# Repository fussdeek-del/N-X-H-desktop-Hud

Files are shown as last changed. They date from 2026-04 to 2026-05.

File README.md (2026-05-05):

# N X H — The Desktop HUD

     

> A always-on hardware HUD that sits on ur desk and shows live CPU, RAM, DISK, FPS and TIME — no alt-tabbing, no task manager, just plug and go.

---

## What is it?

NXH is a compact always-on HUD built around the Raspberry Pi Pico. It plugs into any PC via USB-C and shows live system stats CPU usage, RAM, disk, FPS, and time on a 2.4" ST7789V TFT display (240×320, SPI). The whole thing sits in a custom 3D-printed enclosure I designed in FreeCAD. No software window to manage, no hotkeys, it is just always there on ur desk showing you what ur PC is doing.

## Why I built it

My PC isn't that powerful tbh. Whenever I push it on gaming, rendering, compiling I always needed to know if it's hitting the limit. Opening task manager takes too long and gets in the way. I wanted something that just *sits there* and tells me. So I built it. Hack Club gave me the chance to actually do it for real, with a proper coustum PCBs and everything. Huge shout out to them 🙌

---

## Demo

<p align="center">
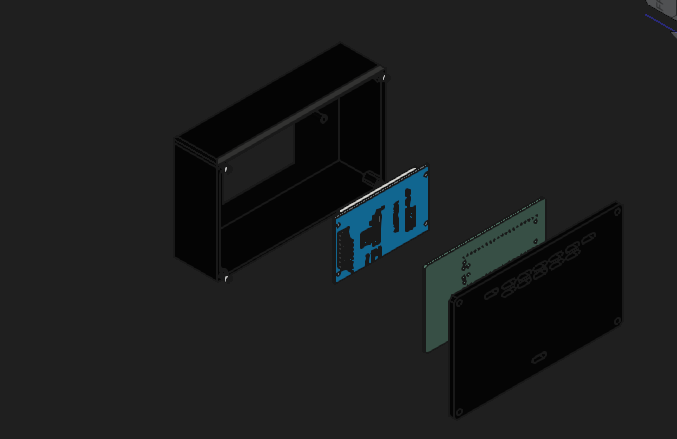
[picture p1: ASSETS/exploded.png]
Exploded 3D view
  
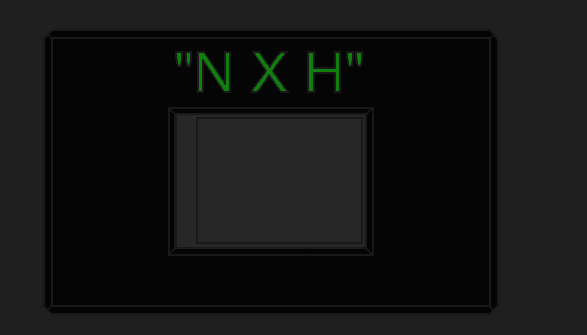
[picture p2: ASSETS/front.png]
Front panel view
  
</p>

<p align="center">
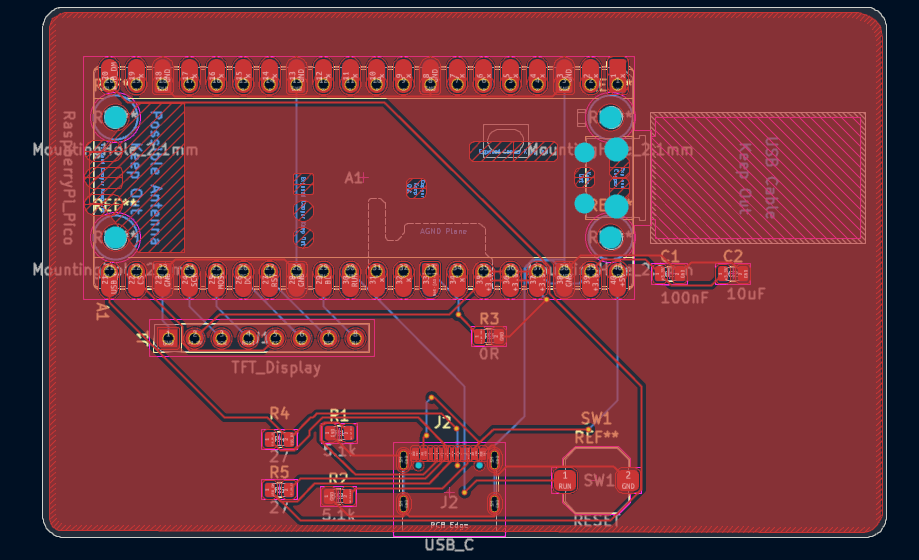
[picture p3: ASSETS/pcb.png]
PCB layout
  
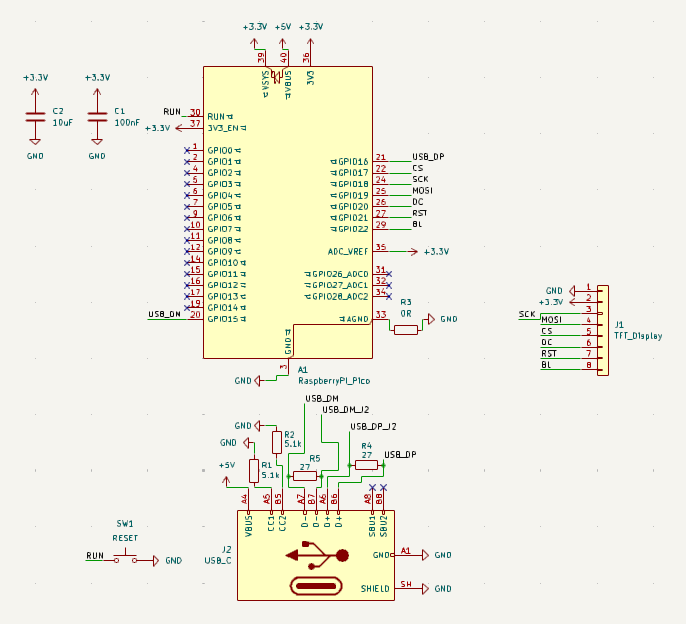
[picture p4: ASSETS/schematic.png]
Full schematic
  
</p>

<p align="center">
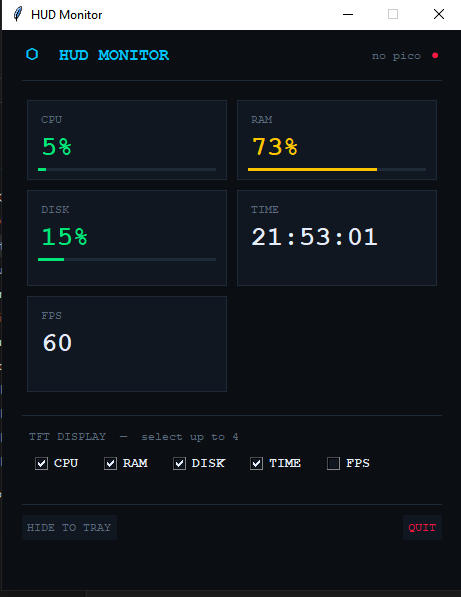
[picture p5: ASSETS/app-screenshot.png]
HUD Monitor companion app
  
</p>

---

## Features

- Raspberry Pi Pico (RP2040) as the main MCU
- 2.4" ST7789V TFT display  240×320, SPI, 3.3V
- USB-C connectivity (power + data, no drivers needed)
- Custom 2-layer PCB designed from scratch in KiCad
- 3D-printed enclosure designed in FreeCAD back lid, front panel, internal mounts
- C++ firmware running on the Pico
- Lightweight companion desktop app (Python) select which stats to display
- Hardware reset button (SW1) wired to RUN pin
- Onboard decoupling capacitors on the 3.3V rail (100nF + 10µF)
- Displays: CPU %, RAM %, Disk %, FPS, System Time

---

## Hardware

| Component | Spec | Qty | Price | Link |
|---|---|---|---|---|
| Raspberry Pi Pico | RP2040, 2MB flash — must be original with TP1/TP2/TP3 test pads | ×1 | $3.53 | [Buy](https://www.aliexpress.com/item/1005008948799927.html) |
| 2.4" TFT Display | ST7789V driver, 240×320, SPI, 8-pin, 3.3V | ×1 | $4.47 | [Buy](https://www.aliexpress.com/item/1005009546154656.html) |
| USB-C Connector | Female SMD 16-pin, horizontal mount, USB 2.0 — GCT USB4105-GF-A footprint | ×1 (pack of 5) | $1.17 | [Buy](https://www.aliexpress.com/item/1005008515699009.html) |
| Resistor 5.1kΩ 0805 | R1, R2 — CC1/CC2 USB-C pull-downs | ×2 (pack of 100) | $1.72 | [Buy](https://www.aliexpress.com/item/1005009613956367.html) |
| Resistor 27Ω 0805 | R4, R5 — USB D+/D− series resistors | ×2 (pack of 100) | $0.46 | [Buy](https://www.aliexpress.com/item/32997835881.html) |
| Resistor 0Ω 0805 | R3 — AGND to GND bridge jumper | ×1 (pack of 100) | $0.71 | [Buy](https://www.aliexpress.com/item/1005007446894308.html) |
| Capacitor 100nF 0805 | C1 — 3.3V rail decoupling, 50V X7R ceramic | ×1 (pack of 100) | $6.11 | [Buy](https://www.aliexpress.com/item/1005012084340996.html) |
| Capacitor 10µF 0805 | C2 — 3.3V rail bulk cap, 10V X5R ceramic | ×1 (pack of 50) | $2.30 | [Buy](https://www.aliexpress.com/item/32911735940.html) |
| Tactile Push Button | 6×6mm SMD 4-pin, 4.3mm height — SW1 reset | ×1 (pack of 20) | $1.95 | [Buy](https://www.aliexpress.com/item/1005006870418414.html) |
| Male Pin Header 2.54mm | Single row 40-pin (snap to 8) — J1 TFT connector | ×1 | $0.90 | [Buy](https://www.aliexpress.com/item/32670970932.html) |
| PCB Manufacturing | 2-layer, FR-4, 1.6mm, HASL — upload Gerber to JLCPCB | ×5 boards | $3.00 | [JLCPCB](https://jlcpcb.com) |
| 3D Enclosure | Custom HUD case — upload STL to JLC3DP | ×1 | $16.78 | [JLC3DP](https://jlc3dp.com) |
| M2 × 6mm Screw + Nut | Stainless steel — 4 sets mount PCB and Pico to case posts | ×4 sets (kit of 50) | $0.30 | [Buy](https://www.aliexpress.com/item/1005003157957734.html) |
| M3 × 10mm Screw + Nut | Stainless steel — 4 sets close the back lid | ×4 sets (kit of 50) | $0.30 | [Buy](https://www.aliexpress.com/item/1005003157957734.html) |
| USB-A to USB-C Cable | 1m, data + power capable (not charge-only) | ×1 | $1.90 | [Buy](https://www.aliexpress.com/item/1005006121990031.html) |
| USB-C Extension Cable | USB-C 3.1 Gen2, PD 100W, 5A — optional if ur port is hard to reach | ×1 | $2.42 | [Buy](https://www.aliexpress.com/item/1005006904002741.html) |

[`BOM components.csv`](BOM%20components.csv)

---

## How to use

## Build & Installation Guide

### Parts needed
See full BOM table above with links.

### PCB Assembly
1. Order PCB using gerbers.zip from JLCPCB
2. Solder SMD components first: R1, R2 (5.1k), R3 (0Ω), R4, R5 (27Ω), C1 (100nF), C2 (10uF), SW1
3. Solder USB-C connector J2
4. Place Raspberry Pi Pico on pin headers
5. Connect TFT display to J1 connector

### Flash Firmware
1. Hold BOOTSEL on Pico and plug USB-C
2. Copy FIRMWARE/hud-firmware/SRC/main.cpp compiled .uf2 to the drive
3. Pico reboots automatically

### Run the companion app

1. Make sure Python is installed — if not, [download it here](https://python.org)
2. Install dependencies:
   ```
   pip install -r app/requirements.txt
   ```
3. Run the app:
   ```
   python app/main.py
   ```
4. The HUD Monitor window opens — tick which stats you want shown on the display (CPU, RAM, DISK, TIME, FPS)
5. The device updates in real time as long as it's connected

> The app talks to the Pico over serial (USB). If it says "no pico" in the top right, unplug and replug the USB-C cable.

---

## Repo structure

```
NXH/
├── README.md
├── BOM components.csv
│
├── APP/
│   └── hud-app/
│       ├── main.py
│       ├── config.py
│       ├── metrics.py
│       ├── tray.py
│       ├── hud_settings.json
│       └── core/
│           ├── formatter.py
│           ├── metrics.py
│           ├── sender.py
│           └── __init__.py
│
├── ASSETS/
│   ├── banner.png
│   ├── exploded.png
│   ├── front.png
│   ├── pcb.png
│   ├── schematic.png
│   ├── app-screenshot.png
│   ├── wiring.png
│   └── zine-page.png
│
├── CAD/
│   ├── HUD case neww.FCStd          ← FreeCAD source
│   ├── HUD case new.step            ← full assembly export
│   ├── PCB new.step                 ← PCB 3D model
│   └── Display TFT-ST7789-240X320 V2.step
│
├── FIRMWARE/
│   └── hud-firmware/
│       ├── platformio.ini
│       └── SRC/
│           └── main.cpp
│
└── PCB/
    ├── gerber new.zip               ← submit this to JLCPCB
    └── PCB new/
        ├── real PCB.kicad_pro
        ├── real PCB.kicad_sch
        └── real PCB.kicad_pcb
```
---

## Wiring diagram

| Pico pin | TFT pin | Signal |
|---|---|---|
| GP17 | CS | Chip select |
| GP18 | SCK | SPI clock |
| GP19 | MOSI | SPI data |
| GP20 | DC | Data/command |
| GP21 | RST | Reset |
| GP22 | BL | Backlight |
| 3V3 (pin 36) | VCC | 3.3V power |
| GND (pin 38) | GND | Ground |

---

## Zine page

*Made for Hack Club Fallout -- Shenzhen 2025*

<p align="center">
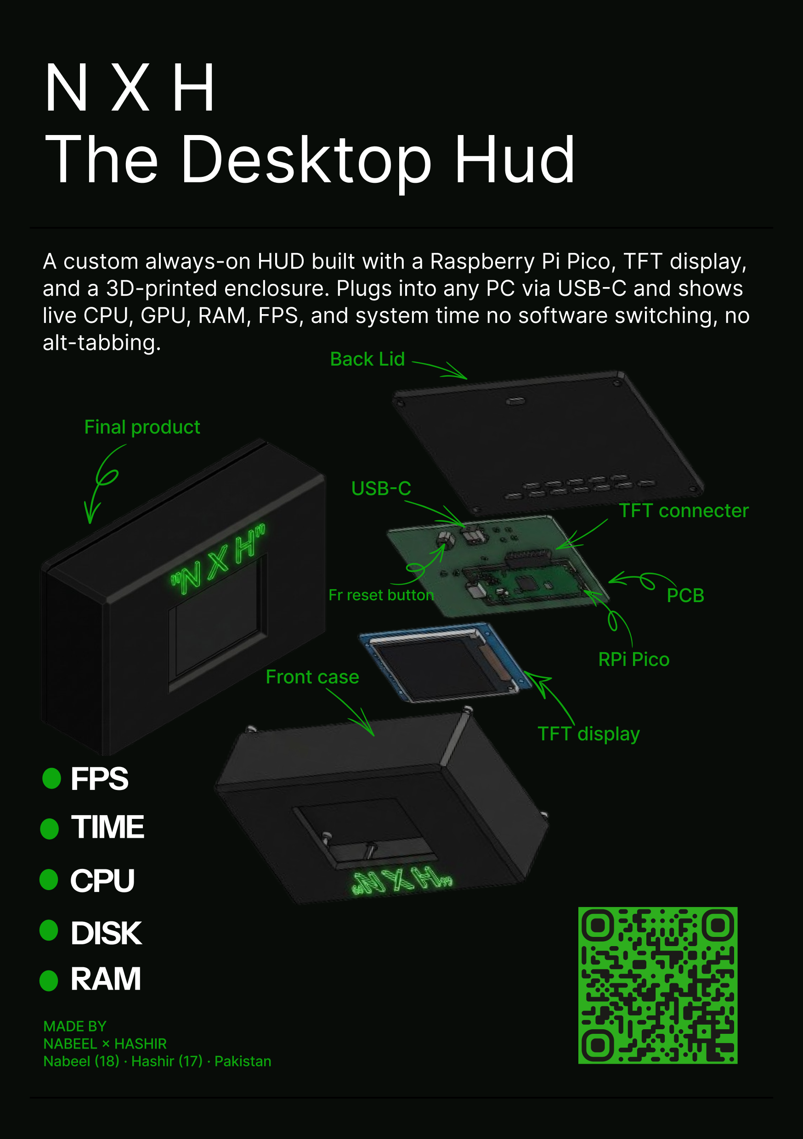
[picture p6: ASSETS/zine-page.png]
NXH Zine page — Nabeel x Hashir, Pakistan
  
</p>

---

## Credits

- [KiCad](https://www.kicad.org/) — PCB design and schematic
- [FreeCAD](https://www.freecad.org/) — 3D enclosure design
- [Hack Club Fallout](https://fallout.hackclub.com) — grant program that made this real
- Python + psutil — companion app backend

Made with love by **Nabeel (18) × Hashir (17)** — Pakistan 🇵🇰

---

## License

This project is licensed under the [MIT License](LICENSE).

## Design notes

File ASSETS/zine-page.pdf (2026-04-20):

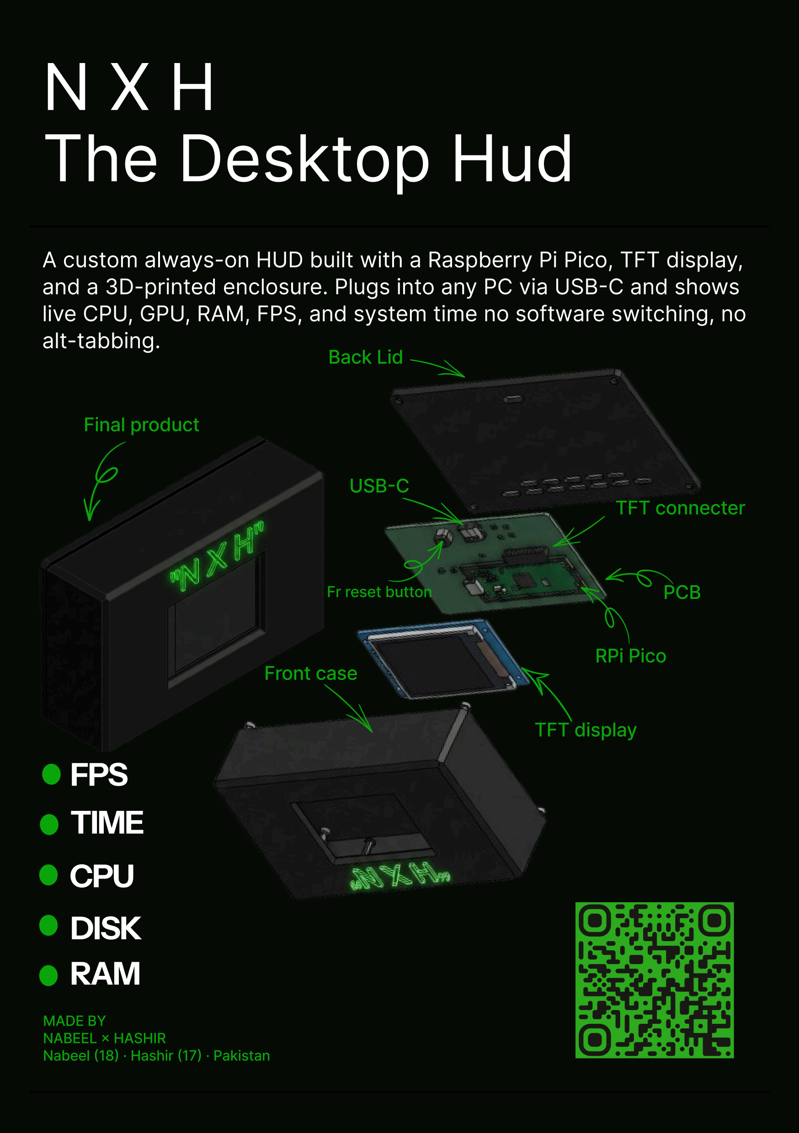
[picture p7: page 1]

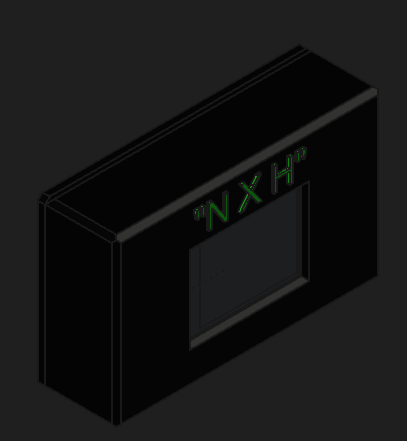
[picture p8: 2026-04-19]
ASSETS/side top.png

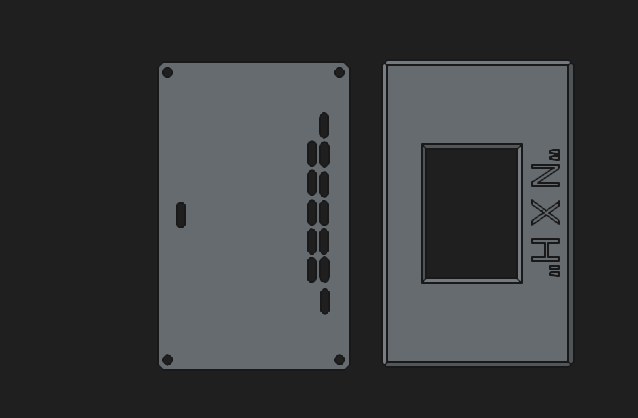
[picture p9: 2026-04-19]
ASSETS/case top.png

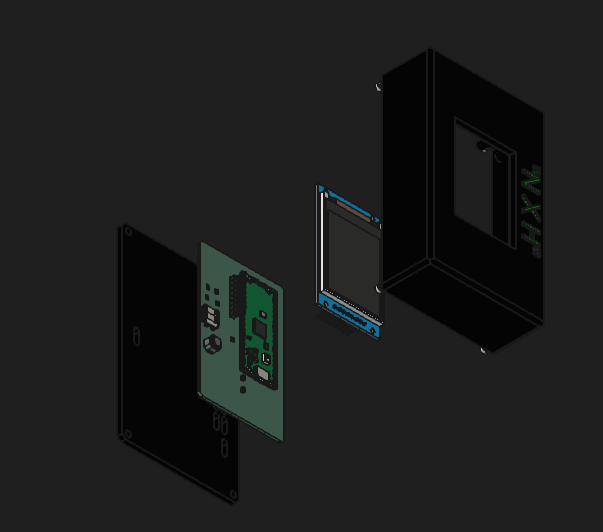
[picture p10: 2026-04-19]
ASSETS/exploded 1.png

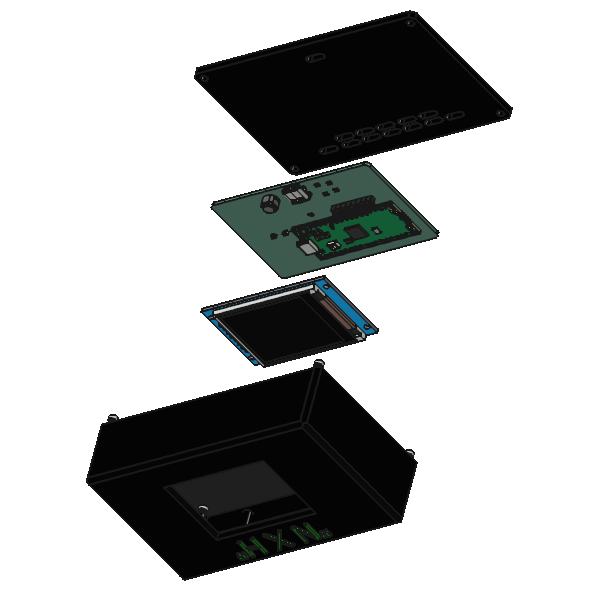
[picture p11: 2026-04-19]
ASSETS/exploded 3.png

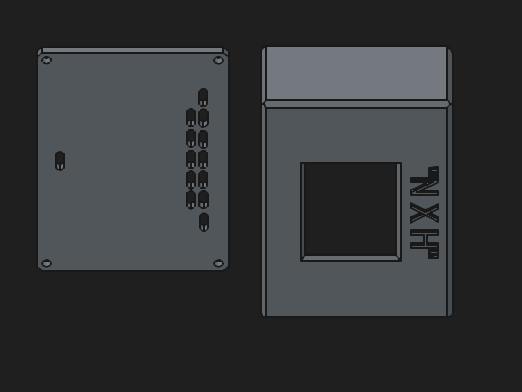
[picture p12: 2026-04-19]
ASSETS/case top edge.png

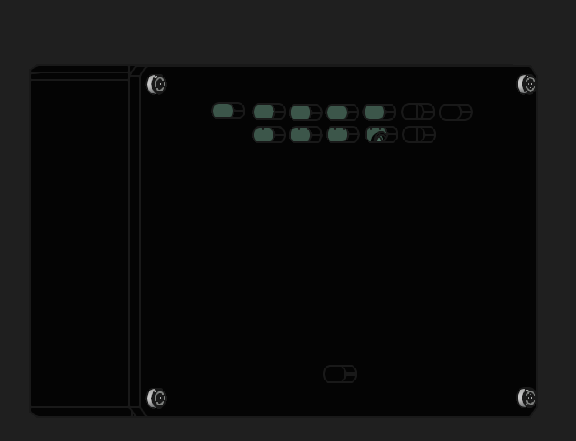
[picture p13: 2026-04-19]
ASSETS/side back.png

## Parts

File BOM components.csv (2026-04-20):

Components | spec | Quantity | Link to buy | Price | Total | Must read notes
Raspberry Pi Pico | RP2040, micro-USB, 2MB flash, original Raspberry Pi Must be original needs TP1 TP2 TP3 test pads on bottom | x1 | https://www.aliexpress.com/item/1005008948799927.html | $3.53
2.4" TFT Display | ST7789V driver, 240×320, SPI, 8-pin, 3.3V Pins: GND VCC SCK MOSI CS DC RST BL | x1 | https://www.aliexpress.com/item/1005009546154656.html | $4.47
USB-C Connector | Female SMD 16-pin receptacle, horizontal mount, USB 2.0 Compatible with GCT USB4105-GF-A footprint | x1 (pack of 5) | https://www.aliexpress.com/item/1005008515699009.html | $1.17
Resistor 5.1kΩ 0805 | 5.1kΩ, 0805 SMD, 5%, 1/8W R1 and R2 CC1 CC2 USB-C pull-downs | ×2 (pack of 100) | https://www.aliexpress.com/item/1005009613956367.html | $1.72
Resistor 27Ω 0805 | 27Ω, 0805 SMD, 5%, 1/8W R4 and R5 USB D+ D− series resistors | ×2 (pack of 100) | https://www.aliexpress.com/item/32997835881.html | $0.46
Resistor 0Ω 0805 | 0Ω, 0805 SMD zero ohm jumper R3 AGND to GND bridge | ×1 (pack of 100) | https://www.aliexpress.com/item/1005007446894308.html | $0.71
Capacitor 100nF 0805 | 100nF, 0805 SMD, 50V, X7R ceramic C1 3.3V rail decoupling | ×1 (pack of 100) | https://www.aliexpress.com/item/1005012084340996.html | $3.11
Capacitor 10µF 0805 | 10µF, 0805 SMD, 10V, X5R ceramic C2 3.3V rail bulk capacitor | ×1 (pack of 50) | https://www.aliexpress.com/item/32911735940.html | $2.30
Tactile Push Button | 6×6mm SMD 4-pin, height 4.3mm SW1 reset button | ×1 (pack of 20) | https://www.aliexpress.com/item/1005006870418414.html | $1.95 |  | You only need this if you wants to add reset button.
Male Pin Header 2.54mm | 2.54mm pitch, single row, 40-pin (snap to 8) J1 TFT display connector | x1 | https://www.aliexpress.com/item/32670970932.html | $0.9
PCB Manufacturing | 2-layer, FR-4, 1.6mm, HASL, 5 boards Upload your Gerber zip to JLCPCB | ×5 | jlcpcb.com | $3
3D Enclosure | Custom HUD case, your FreeCAD/STL design Upload STL to JLC3DP | ×1 | jlc3dp.com | $16.78 |  | i am going with resin of my choice, u can get of your own choice it will be cheap.
M2 × 6mm Screw + Nut | M2 × 6mm hex socket head, stainless steel + M2 nuts 4 screws + 4 nuts mount PCB and Pico to case posts | ×4 sets ( kit of 50) | https://www.aliexpress.com/item/1005003157957734.html | $0.3
M3 × 10mm Screw + Nut | M3 × 10mm hex socket head, stainless steel + M3 nuts 4 screws + 4 nuts back lid of 3D enclosure | ×4 sets (buy kit of 50) | https://www.aliexpress.com/item/1005003157957734.html | $0.3
USB-A to USB-C Cable | 1 metre, data + power capable (not charge-only) Everyday cable from PC to your HUD device | ×1 | https://www.aliexpress.com/item/1005006121990031.html | $1.9
USB-C extention | USB C 3.1 Gen2 10Gbps Extension Cable Type C to C PD 100W QC4.0 3.0 5A Fast Charging Cable | x1 | https://www.aliexpress.com/item/1005006904002741.html | $2.42 |  | I am using this because o want to my USB port on back, u can customize your design
 |  |  |  |  | $45.02

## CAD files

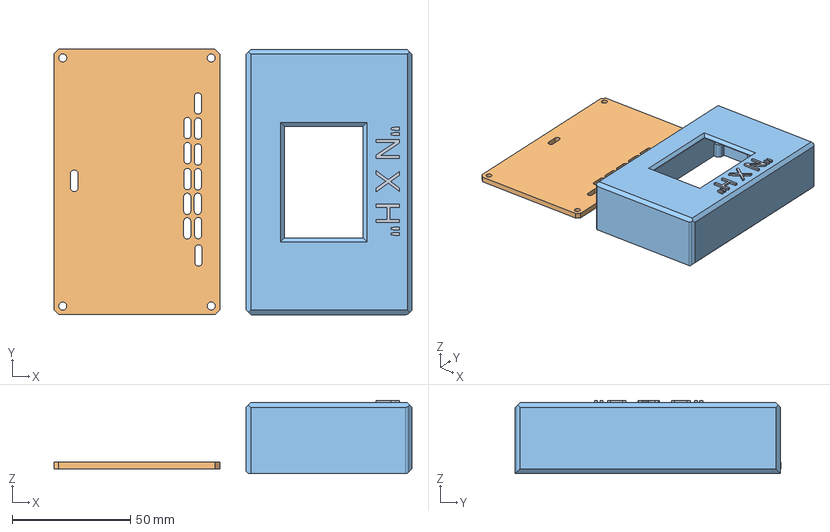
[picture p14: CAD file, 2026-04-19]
CAD/HUD case neww.FCStd
151.1 x 112.1 x 31.0 mm
front logo
back lid
main case

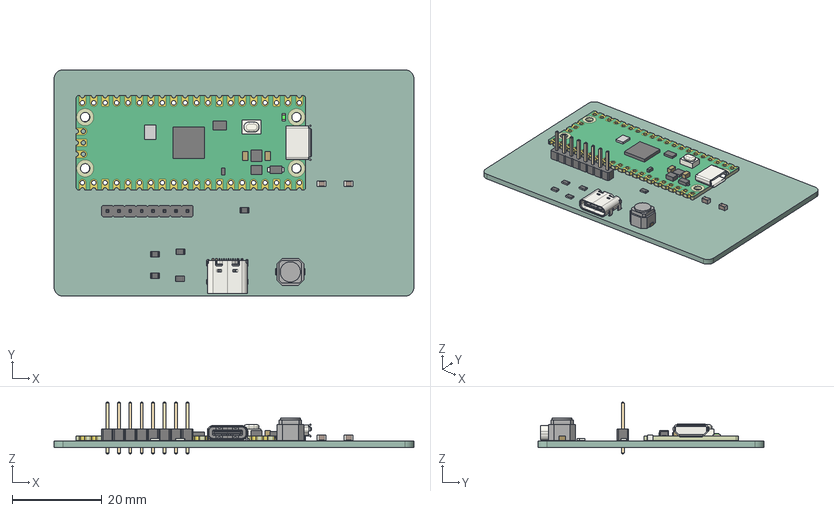
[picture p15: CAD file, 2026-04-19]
CAD/PCB new.step
80.1 x 50.3 x 11.5 mm
C_0805_2012Metric x 2
RaspberryPi_Pico_Module_KiCad
pin_1
pin_2
R_0805_2012Metric x 5
USB_C_Receptacle_GCT_USB4105-xx-A_16P_TopMnt_Horizontal
PinHeader_1x08_P2.54mm_Vertical
real PCB_PCB

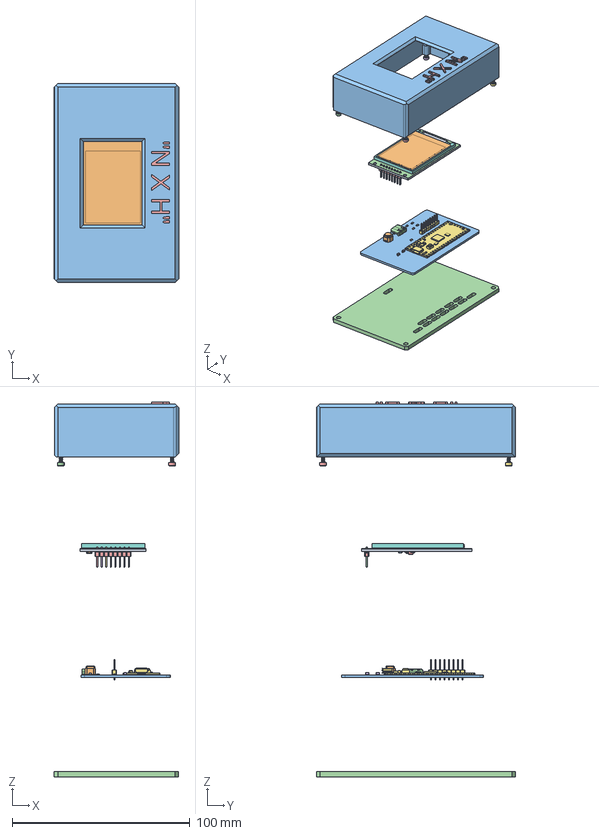
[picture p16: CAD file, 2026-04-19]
CAD/mycase renew.FCStd
70.1 x 112.1 x 211.0 mm
Board
64-copper
1-soldermask
64-soldermask
6130xx11121_PIN
6130xx11121_PIN001
6130xx11121_PIN002
6130xx11121_PIN003
6130xx11121_PIN004
6130xx11121_PIN005
6130xx11121_PIN006
6130xx11121_PIN007
SOT23
DIODE_PGB-0603MP
DIODE_PGB-0603MP001
DIODE_PGB-0603MP002
DIODE_PGB-0603MP003
DIODE_PGB-0603MP004
5576557.f3d
5576557.f3d 001
5576557.f3d 002
5576557.f3d 003
5576557.f3d 004
5576557.f3d 005
5576557.f3d 006
CAP_0603
CAP_0604
SOT89
1-copper
Text
Screen support
Ribon cable
Glass
main body
back LID
name on case
C_0805_2012Metric
RaspberryPi_Pico_Module_KiCad
pin_1
pin_2
R_0805_2012Metric
USB_C_Receptacle_GCT_USB4105-xx-A_16P_TopMnt_Horizontal
R_0805_2012Metric001
C_0805_2012Metric001
PinHeader_1x08_P2.54mm_Vertical
R_0805_2012Metric002
R_0805_2012Metric003
R_0805_2012Metric004
real PCB_PCB
nuts 1
nuts 2
nuts 3
nuts 4

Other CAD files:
CAD/HUD case new.step

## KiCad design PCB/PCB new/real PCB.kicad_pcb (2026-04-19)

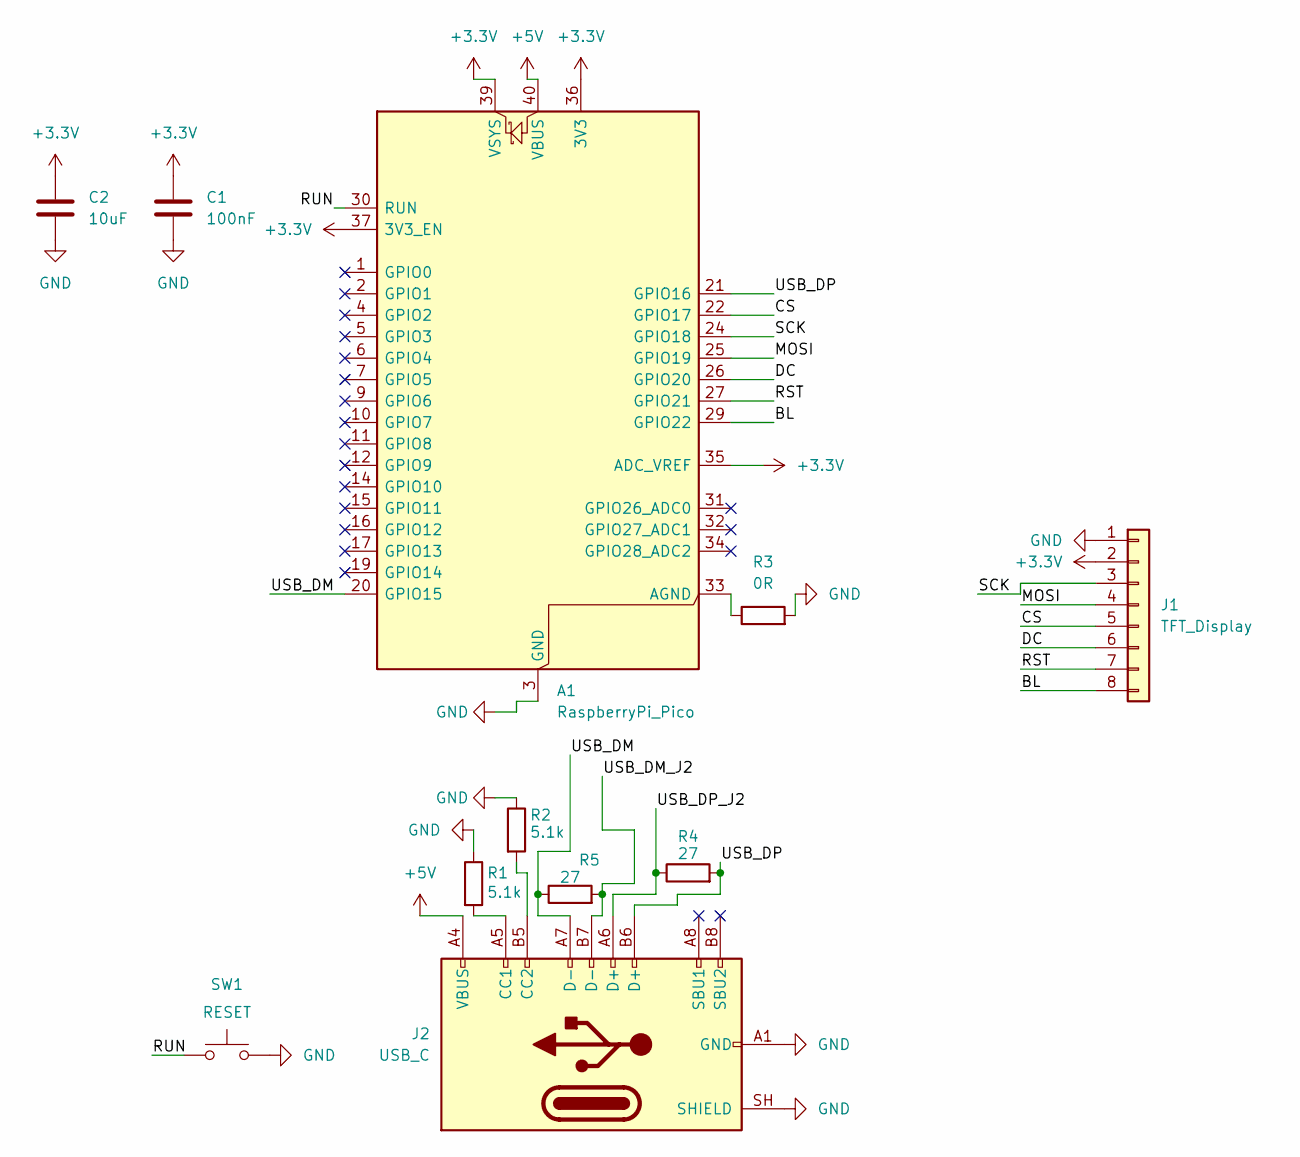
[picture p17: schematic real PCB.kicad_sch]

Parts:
A1: RaspberryPi_Pico; RaspberryPi_Pico_Common_Unspecified
C1: 100nF; C_0805_2012Metric
C2: 10uF; C_0805_2012Metric
J1: TFT_Display; PinHeader_1x08_P2.54mm_Vertical
J2: USB_C; USB_C_Receptacle_GCT_USB4105-xx-A_16P_TopMnt_Horizontal
R1, R2: 5.1k; R_0805_2012Metric
R3: 0R; R_0805_2012Metric
R4, R5: 27; R_0805_2012Metric
SW1: RESET; SW_Push_1TS009xxxx-xxxx-xxxx_6x6x5mm

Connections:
+3.3V: A1.35 (ADC_VREF), A1.36 (3V3), A1.37 (3V3_EN), A1.39 (VSYS), C1.1, C2.1, J1.2
+5V: A1.40 (VBUS), J2.A4 (VBUS), J2.A9 (VBUS), J2.B4 (VBUS), J2.B9 (VBUS)
/BL: A1.29 (GPIO22), J1.8
/CS: A1.22 (GPIO17), J1.5
/DC: A1.26 (GPIO20), J1.6
/MOSI: A1.25 (GPIO19), J1.4
/RST: A1.27 (GPIO21), J1.7
/RUN: A1.30 (RUN), SW1.1
/SCK: A1.24 (GPIO18), J1.3
/USB_DM: A1.20 (GPIO15), J2.A7 (D-), R5.1
/USB_DM_J2: J2.B7 (D-), R5.2
/USB_DP: A1.21 (GPIO16), J2.B6 (D+), R4.2
/USB_DP_J2: J2.A6 (D+), R4.1
GND: A1.3 (GND), A1.8 (GND), A1.13 (GND), A1.18 (GND), A1.23 (GND), A1.28 (GND), A1.38 (GND), C1.2, C2.2, J1.1, J2.A1 (GND), J2.A12 (GND), J2.B1 (GND), J2.B12 (GND), J2.SH (SHIELD), R1.1, R2.1, R3.2, SW1.2
unnamed: A1.33 (AGND), R3.1
unnamed: J2.A5 (CC1), R1.2
unnamed: J2.B5 (CC2), R2.2

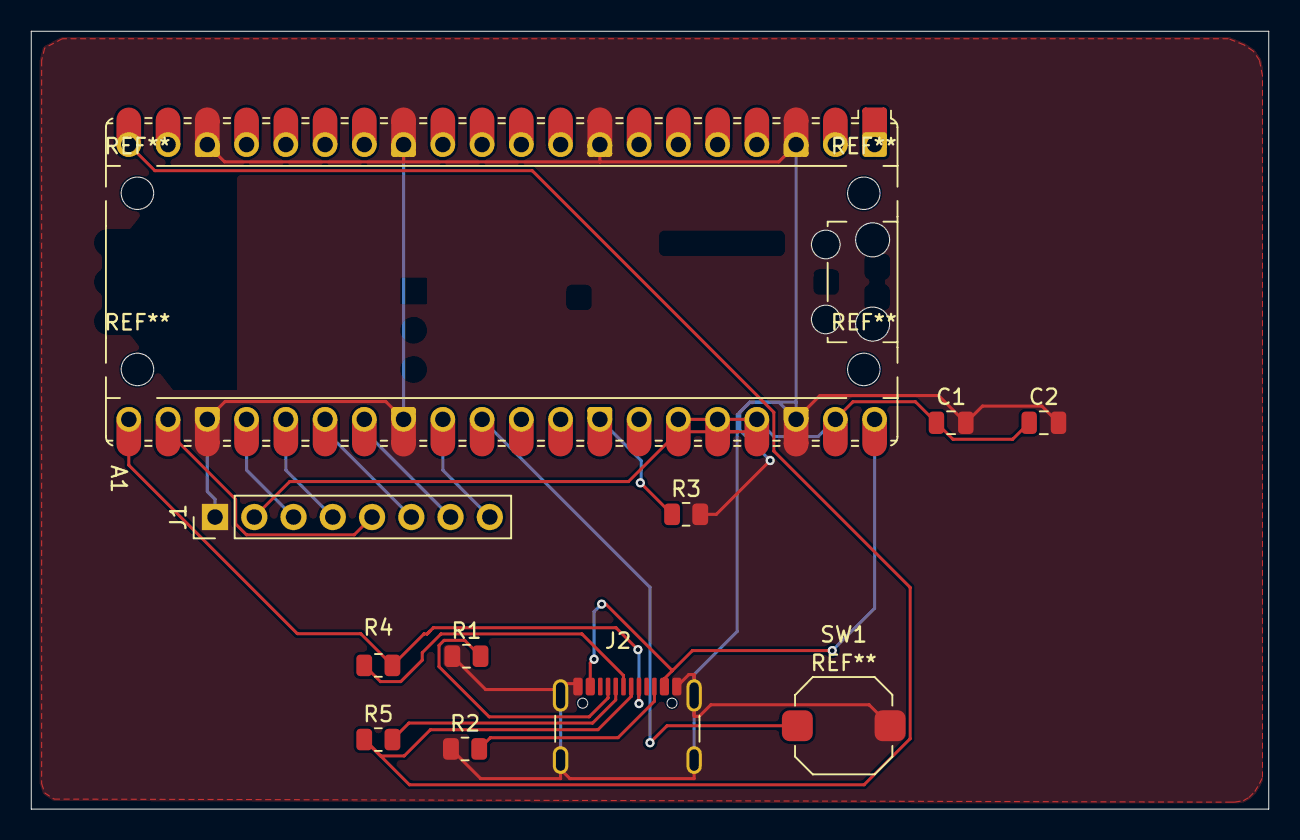
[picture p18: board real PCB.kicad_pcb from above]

Board: 2 copper layers, 80.1 x 50.3 mm, 11 parts (0 on the bottom side), 17 nets.

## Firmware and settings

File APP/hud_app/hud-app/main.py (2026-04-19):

"""
HUD Monitor , 
Tray icon + minimal UI + metric selector + serial sender to Pico TFT
"""

import ctypes
import json
import os
import sys
import threading
import time
import tkinter as tk
from tkinter import font as tkfont

# optional tray (pystray + Pillow) 
try:
    import pystray
    from PIL import Image, ImageDraw
    HAS_TRAY = True
except ImportError:
    HAS_TRAY = False

 
#  serial
try:
    import serial
    from serial.tools import list_ports
except ImportError:
    serial = None
    list_ports = None


#  psutil 
import psutil


# CONFIG

UPDATE_MS          = 1000
SERIAL_BAUD        = 115200
SERIAL_RETRY_S     = 3
SERIAL_PORT        = None          # None = auto-detect Pico
MAX_TFT_METRICS    = 4
SETTINGS_FILE      = os.path.join(os.path.dirname(__file__), "hud_settings.json")
SINGLE_INSTANCE    = "HUDMonitorSingleInstanceMutex"

ALL_METRICS = ["CPU", "RAM", "DISK", "TIME", "FPS"]


#  colours 

BG          = "#0b0f14"
CARD        = "#111720"
BORDER      = "#1e2a38"
ACCENT      = "#00c6ff"
ACCENT2     = "#0072ff"
TEXT        = "#e4ecf7"
MUTED       = "#5a6a80"
GREEN       = "#00e676"
RED         = "#ff1744"
WARN        = "#ffc400"



# HELPERS

class DEVMODEW(ctypes.Structure):
    _fields_ = [
        ("dmDeviceName",        ctypes.c_wchar * 32),
        ("dmSpecVersion",       ctypes.c_ushort),
        ("dmDriverVersion",     ctypes.c_ushort),
        ("dmSize",              ctypes.c_ushort),
        ("dmDriverExtra",       ctypes.c_ushort),
        ("dmFields",            ctypes.c_ulong),
        ("dmPositionX",         ctypes.c_long),
        ("dmPositionY",         ctypes.c_long),
        ("dmDisplayOrientation",ctypes.c_ulong),
        ("dmDisplayFixedOutput",ctypes.c_ulong),
        ("dmColor",             ctypes.c_short),
        ("dmDuplex",            ctypes.c_short),
        ("dmYResolution",       ctypes.c_short),
        ("dmTTOption",          ctypes.c_short),
        ("dmCollate",           ctypes.c_short),
        ("dmFormName",          ctypes.c_wchar * 32),
        ("dmLogPixels",         ctypes.c_ushort),
        ("dmBitsPerPel",        ctypes.c_ulong),
        ("dmPelsWidth",         ctypes.c_ulong),
        ("dmPelsHeight",        ctypes.c_ulong),
        ("dmDisplayFlags",      ctypes.c_ulong),
        ("dmDisplayFrequency",  ctypes.c_ulong),
        ("dmICMMethod",         ctypes.c_ulong),
        ("dmICMIntent",         ctypes.c_ulong),
        ("dmMediaType",         ctypes.c_ulong),
        ("dmDitherType",        ctypes.c_ulong),
        ("dmReserved1",         ctypes.c_ulong),
        ("dmReserved2",         ctypes.c_ulong),
        ("dmPanningWidth",      ctypes.c_ulong),
        ("dmPanningHeight",     ctypes.c_ulong),
    ]


def get_refresh_rate():
    try:
        dm = DEVMODEW()
        dm.dmSize = ctypes.sizeof(DEVMODEW)
        if ctypes.windll.user32.EnumDisplaySettingsW(None, -1, ctypes.byref(dm)):
            return int(dm.dmDisplayFrequency or 60)
    except Exception:
        pass
    return 60


def get_main_drive():
    drive = os.path.splitdrive(os.getcwd())[0]
    return f"{drive}\\" if drive else "C:\\"


def collect_metrics():
    from datetime import datetime
    return {
        "CPU":  f"{int(round(psutil.cpu_percent(interval=None)))}%",
        "RAM":  f"{int(round(psutil.virtual_memory().percent))}%",
        "DISK": f"{int(round(psutil.disk_usage(get_main_drive()).percent))}%",
        "TIME": datetime.now().strftime("%H:%M:%S"),
        "FPS":  str(get_refresh_rate()),
    }


# prime cpu
psutil.cpu_percent(interval=None)



# SETTINGS  (persist selected metrics)

def load_settings():
    try:
        with open(SETTINGS_FILE) as f:
            data = json.load(f)
            sel = [m for m in data.get("selected", ALL_METRICS) if m in ALL_METRICS]
            return sel[:MAX_TFT_METRICS] if sel else ALL_METRICS[:MAX_TFT_METRICS]
    except Exception:
        return ALL_METRICS[:MAX_TFT_METRICS]


def save_settings(selected):
    try:
        with open(SETTINGS_FILE, "w") as f:
            json.dump({"selected": selected}, f)
    except Exception:
        pass


# SERIAL SENDER
# 

class SerialSender:
    def __init__(self):
        self.conn = None
        self.last_try = 0.0

    def send(self, line):
        if not self._write(line):
            pass  # silent — no cmd spam

    def close(self):
        if self.conn:
            try: self.conn.close()
            except Exception: pass
            self.conn = None

    def connected(self):
        return self.conn is not None

    def _write(self, line):
        if serial is None: return False
        if not self.conn and not self._connect(): return False
        try:
            self.conn.write(line.encode("ascii"))
            return True
        except Exception:
            self.close()
            return False

    def _connect(self):
        now = time.monotonic()
        if now - self.last_try < SERIAL_RETRY_S: return False
        self.last_try = now
        for port in self._ports():
            try:
                self.conn = serial.Serial(port=port, baudrate=SERIAL_BAUD, timeout=0, write_timeout=0)
                return True
            except Exception:
                self.conn = None
        return False

    def _ports(self):
        if SERIAL_PORT: return [SERIAL_PORT]
        if list_ports is None: return []
        pref, fall = [], []
        for p in list_ports.comports():
            txt = " ".join(x for x in (p.device, p.description, p.manufacturer) if x).lower()
            if any(t in txt for t in ("rp2040", "pico", "tinyusb", "cdc", "usb serial")):
                pref.append(p.device)
            else:
                fall.append(p.device)
        return pref + fall



# FORMAT payload → serial line  (only sends selected metrics)

def format_for_tft(metrics, selected):
    KEY_MAP = {"CPU": "CPU", "RAM": "RAM", "DISK": "DISK", "TIME": "TIME", "FPS": "FPS"}
    parts = []
    for key in selected:
        val = metrics.get(key, "--").replace("%", "")
        parts.append(f"{KEY_MAP[key]}:{val}")
    return ";".join(parts) + ";\n"



# TRAY ICON  (build a small icon with Pillow)

def make_tray_icon():
    size = 64
    img = Image.new("RGBA", (size, size), (0, 0, 0, 0))
    d = ImageDraw.Draw(img)
    d.ellipse([4, 4, size-4, size-4], fill="#00c6ff")
    d.rectangle([20, 28, 44, 36], fill="#0b0f14")
    d.rectangle([28, 20, 36, 44], fill="#0b0f14")
    return img



# MAIN UI WINDOW

class HUDWindow:
    def __init__(self, sender: SerialSender):
        self.sender   = sender
        self.selected = load_settings()
        self.metrics  = {}
        self.running  = True

        self.root = tk.Tk()
        self.root.title("HUD Monitor")
        self.root.configure(bg=BG)
        self.root.geometry("460x560")
        self.root.resizable(False, False)
        self.root.overrideredirect(False)

        # keep on top toggle — off by default
        self.root.attributes("-topmost", False)

        # close = hide to tray (if tray available), else quit
        self.root.protocol("WM_DELETE_WINDOW", self._hide)

        self._build_ui()
        self._start_bg_thread()

        if HAS_TRAY:
            self._start_tray()

    
    #  UI BUILD 

    def _build_ui(self):
        root = self.root

        
        #  title bar 

        title_bar = tk.Frame(root, bg=BG, pady=12)
        title_bar.pack(fill="x", padx=20)

        tk.Label(title_bar, text="⬡  HUD MONITOR", bg=BG, fg=ACCENT,
                 font=("Courier New", 13, "bold")).pack(side="left")

        self.status_dot = tk.Label(title_bar, text="●", bg=BG, fg=MUTED,
                                   font=("Courier New", 10))
        self.status_dot.pack(side="right")
        self.status_lbl = tk.Label(title_bar, text="disconnected", bg=BG, fg=MUTED,
                                   font=("Courier New", 8))
        self.status_lbl.pack(side="right", padx=(0, 4))

        tk.Frame(root, bg=BORDER, height=1).pack(fill="x", padx=20)

         
        #  live stats cards 
        
        stats_frame = tk.Frame(root, bg=BG)
        stats_frame.pack(fill="x", padx=20, pady=14)

        self.card_labels = {}   # key → (val_label, bar_canvas)
        for i, key in enumerate(ALL_METRICS):
            card = tk.Frame(stats_frame, bg=CARD, bd=0, highlightthickness=1,
                            highlightbackground=BORDER)
            card.grid(row=i//2*2, column=i%2, padx=5, pady=5, sticky="nsew")
            stats_frame.columnconfigure(i%2, weight=1)

            tk.Label(card, text=key, bg=CARD, fg=MUTED,
                     font=("Courier New", 8)).pack(anchor="w", padx=10, pady=(8,0))

            val = tk.Label(card, text="--", bg=CARD, fg=TEXT,
                           font=("Courier New", 20, "bold"))
            val.pack(anchor="w", padx=10)

            # bar (only for CPU/RAM/DISK)
            bar = None
            if key in ("CPU", "RAM", "DISK"):
                bar = tk.Canvas(card, bg=CARD, height=3, bd=0,
                                highlightthickness=0, width=160)
                bar.pack(fill="x", padx=10, pady=(2,8))
            else:
                tk.Label(card, text="", bg=CARD).pack(pady=4)

            self.card_labels[key] = (val, bar)

        tk.Frame(root, bg=BORDER, height=1).pack(fill="x", padx=20, pady=(4,0))

        
        #  TFT selector 
        
        tk.Label(root, text="TFT DISPLAY  —  select up to 4",
                 bg=BG, fg=MUTED, font=("Courier New", 8)).pack(anchor="w", padx=24, pady=(10,4))

        sel_frame = tk.Frame(root, bg=BG)
        sel_frame.pack(fill="x", padx=20)

        self.check_vars = {}
        for key in ALL_METRICS:
            var = tk.BooleanVar(value=(key in self.selected))
            self.check_vars[key] = var

            cb = tk.Checkbutton(
                sel_frame, text=key, variable=var,
                bg=BG, fg=TEXT, selectcolor=CARD,
                activebackground=BG, activeforeground=ACCENT,
                font=("Courier New", 10, "bold"),
                command=self._on_check_change,
                cursor="hand2"
            )
            cb.pack(side="left", padx=8)

        self.sel_warn = tk.Label(root, text="", bg=BG, fg=WARN,
                                 font=("Courier New", 8))
        self.sel_warn.pack(anchor="w", padx=24)

        tk.Frame(root, bg=BORDER, height=1).pack(fill="x", padx=20, pady=(8,0))

        
        #  bottom bar 
        
        bot = tk.Frame(root, bg=BG, pady=10)
        bot.pack(fill="x", padx=20)

        tk.Button(bot, text="HIDE TO TRAY" if HAS_TRAY else "MINIMIZE",
                  bg=CARD, fg=MUTED, relief="flat", cursor="hand2",
                  font=("Courier New", 8),
                  command=self._hide).pack(side="left")

        tk.Button(bot, text="QUIT",
                  bg=CARD, fg=RED, relief="flat", cursor="hand2",
                  font=("Courier New", 8),
                  command=self._quit).pack(side="right")

    
    #  CHECK CHANGE 
    
    def _on_check_change(self):
        selected = [k for k, v in self.check_vars.items() if v.get()]
        if len(selected) > MAX_TFT_METRICS:
            # find last checked and uncheck it
            for k in reversed(ALL_METRICS):
                if self.check_vars[k].get() and k not in self.selected:
                    self.check_vars[k].set(False)
                    break
            selected = [k for k, v in self.check_vars.items() if v.get()]
            self.sel_warn.config(text=f"⚠  Max {MAX_TFT_METRICS} metrics for TFT display")
        else:
            self.sel_warn.config(text="")

        self.selected = selected
        save_settings(self.selected)

    
    #  BACKGROUND THREAD 

    def _start_bg_thread(self):
        t = threading.Thread(target=self._loop, daemon=True)
        t.start()

    def _loop(self):
        while self.running:
            t0 = time.monotonic()
            try:
                self.metrics = collect_metrics()
                line = format_for_tft(self.metrics, self.selected)
                self.sender.send(line)
                self.root.after(0, self._refresh_ui)
            except Exception:
                pass
            elapsed = time.monotonic() - t0
            time.sleep(max(0, UPDATE_MS / 1000 - elapsed))

    
    #  REFRESH UI 

    def _refresh_ui(self):
        for key, (val_lbl, bar) in self.card_labels.items():
            raw = self.metrics.get(key, "--")
            val_lbl.config(text=raw)

            # colour code
            if key in ("CPU", "RAM", "DISK"):
                pct = int(raw.replace("%", "") or 0)
                color = GREEN if pct < 60 else WARN if pct < 85 else RED
                val_lbl.config(fg=color)
                if bar:
                    bar.delete("all")
                    w = bar.winfo_width() or 160
                    filled = int(w * pct / 100)
                    bar.create_rectangle(0, 0, w, 3, fill=BORDER, outline="")
                    if filled > 0:
                        bar.create_rectangle(0, 0, filled, 3, fill=color, outline="")
            else:
                val_lbl.config(fg=TEXT)

        # serial status dot
        if self.sender.connected():
            self.status_dot.config(fg=GREEN)
            self.status_lbl.config(text="pico connected", fg=GREEN)
        else:
            self.status_dot.config(fg=RED)
            self.status_lbl.config(text="no pico", fg=MUTED)

        # update tray tooltip
        if HAS_TRAY and hasattr(self, "tray"):
            cpu = self.metrics.get("CPU", "--")
            ram = self.metrics.get("RAM", "--")
            try:
                self.tray.title = f"HUD  CPU {cpu}  RAM {ram}"
            except Exception:
                pass

    
    #  TRAY 
    
    def _start_tray(self):
        menu = pystray.Menu(
            pystray.MenuItem("Show",   self._show, default=True),
            pystray.MenuItem("Quit",   self._quit),
        )
        self.tray = pystray.Icon("HUD Monitor", make_tray_icon(),
                                 "HUD Monitor", menu)
        t = threading.Thread(target=self.tray.run, daemon=True)
        t.start()

    def _hide(self):
        self.root.withdraw()

    def _show(self, *_):
        self.root.after(0, self.root.deiconify)

    def _quit(self, *_):
        self.running = False
        self.sender.close()
        if HAS_TRAY and hasattr(self, "tray"):
            try: self.tray.stop()
            except Exception: pass
        self.root.after(0, self.root.destroy)

    def run(self):
        self.root.mainloop()



# SINGLE INSTANCE GUARD

def acquire_mutex():
    k = ctypes.windll.kernel32
    m = k.CreateMutexW(None, False, SINGLE_INSTANCE)
    if k.GetLastError() == 183:
        tk.Tk().withdraw()
        import tkinter.messagebox as mb
        mb.showinfo("HUD Monitor", "HUD Monitor is already running.")
        return None
    return m



# ENTRY

def main():
    mutex = acquire_mutex()
    if mutex is None:
        return

    sender = SerialSender()
    app    = HUDWindow(sender)

    try:
        app.run()
    finally:
        sender.close()
        ctypes.windll.kernel32.ReleaseMutex(mutex)


if __name__ == "__main__":
    main()

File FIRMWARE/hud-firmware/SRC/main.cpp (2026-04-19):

// hUD Firmware for RP2040 + ST7789
// reads serial data from PC and displays on TFT

#include <Arduino.h>
#include <Adafruit_GFX.h>
#include <Adafruit_ST7789.h>
#include <SPI.h>

// PIN CONFIG (matched to your PCB schematic) 
#define TFT_CS    17   // GPIO17 - pin 22 on Pico
#define TFT_DC    20   // GPIO20 - pin 26 on Pico
#define TFT_RST   21   // GPIO21 - pin 27 on Pico
#define TFT_BL    22   // GPIO22 - pin 29 on Pico (backlight)

Adafruit_ST7789 tft = Adafruit_ST7789(TFT_CS, TFT_DC, TFT_RST);

//  DATA VARIABLES 
String fps     = "--";
String cpu     = "--";
String ram     = "--";
String disk    = "--";
String timeStr = "--:--:--";

// Keep previous values to avoid redrawing unchanged fields
String prev_fps     = "";
String prev_cpu     = "";
String prev_ram     = "";
String prev_disk    = "";
String prev_time    = "";

// COLORS 
#define COLOR_BG     0x0000   // Black background
#define COLOR_LABEL  0x4A49   // Muted grey for labels
#define COLOR_VALUE  0xFFFF   // White for values
#define COLOR_BOX    0x2124   // Dark box behind each row

//  DRAW ONE ROW (no-flicker: only redraws value if changed) 
void drawRow(int y, const char* label, String value, String& prev, const char* unit = "") {
  if (value == prev) return;  // skip if nothing changed

  // Erase old value area only (not the whole screen)
  tft.fillRect(100, y, 140, 24, COLOR_BG);

  // Draw value
  tft.setTextColor(COLOR_VALUE);
  tft.setTextSize(2);
  tft.setCursor(100, y);
  tft.print(value);
  if (strlen(unit) > 0) tft.print(unit);

  prev = value;
}

//  DRAW STATIC LABELS (called once at startup)
void drawLabels() {
  tft.setTextColor(COLOR_LABEL);
  tft.setTextSize(2);

  tft.setCursor(10, 20);  tft.print("FPS :");
  tft.setCursor(10, 60);  tft.print("CPU :");
  tft.setCursor(10, 100); tft.print("RAM :");
  tft.setCursor(10, 140); tft.print("DSK :");
  tft.setCursor(10, 190); tft.print("TIME:");
}

//  PARSE INCOMING SERIAL LINE 
void parseData(String data) {
  int start;

  start = data.indexOf("FPS:");
  if (start != -1) fps = data.substring(start + 4, data.indexOf(';', start));

  start = data.indexOf("CPU:");
  if (start != -1) cpu = data.substring(start + 4, data.indexOf(';', start));

  start = data.indexOf("RAM:");
  if (start != -1) ram = data.substring(start + 4, data.indexOf(';', start));

  start = data.indexOf("DISK:");
  if (start != -1) disk = data.substring(start + 5, data.indexOf(';', start));

  start = data.indexOf("TIME:");
  if (start != -1) timeStr = data.substring(start + 5, data.indexOf(';', start));
}

//  SETUP 
void setup() {
  Serial.begin(115200);

  // Turn on backlight
  pinMode(TFT_BL, OUTPUT);
  digitalWrite(TFT_BL, HIGH);

  // Init display
  tft.init(240, 240);
  tft.setRotation(0);
  tft.fillScreen(COLOR_BG);

  // Draw static labels once
  drawLabels();
}

//  LOOP 
void loop() {
  if (Serial.available()) {
    String data = Serial.readStringUntil('\n');
    parseData(data);

    // only redraws rows where value actually changed — no flicke
    drawRow(20,  "FPS :", fps,     prev_fps);
    drawRow(60,  "CPU :", cpu,     prev_cpu,  "%");
    drawRow(100, "RAM :", ram,     prev_ram,  "%");
    drawRow(140, "DSK :", disk,    prev_disk, "%");
    drawRow(190, "TIME:", timeStr, prev_time);
  }
}

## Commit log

2026-04-19 Revise project structure in README
    Updated project structure and added new directories for BOM, APP, ASSETS, CAD, FIRMWARE, and PCB.
2026-04-19 Update README with wiring diagram and zine page
    Added wiring diagram and zine page sections to README.
2026-04-19 Remove sections from README.md
    Removed wiring diagram, zine page, credits, and license sections from the README.
2026-04-19 Update README with wiring diagram and credits
    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
2026-04-19 initial project upload
    initial project upload
    [BOM components.csv, HUD case new.step, HUD case neww.FCStd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]
2026-04-20 Update BOM file link in README
2026-04-20 Fix link to BOM components in README.md
2026-04-20 Update pin assignments for TFT display in README
2026-04-20 Fix link formatting for BOM components in README
2026-04-20 Revise README with installation and assembly details
    Updated the README to include a build and installation guide, parts needed, and PCB assembly instructions.
2026-04-20 Clean up wiring diagram section in README
    Removed HTML tags around the wiring diagram image.
2026-04-20 update bom prices
    [BOM components.csv]
2026-04-20 Update BOM components.csv
    [BOM components.csv]

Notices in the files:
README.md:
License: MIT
